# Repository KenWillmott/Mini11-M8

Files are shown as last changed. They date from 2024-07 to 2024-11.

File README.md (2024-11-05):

# Mini11-M8
MC68HC11A1 MCU based SBC

## IMPORTANT! This project is deprecated. It's superceded by this device:
https://github.com/KenWillmott/Mini11-M8E

This project is based on hardware and software developed here:
https://github.com/EtchedPixels/Mini11

# Overview
This is a 10cm * 10cm PCB with an MC68HC11A1 processor. It uses only traditional through hole PCB construction and MSI glue logic in the 74HC line. It does not have any programmable logic device other than the usual EEPROM. There is one exception, the reset controller is an SMD device. This is because of a noticeable cost/availability problem with through hole type reset controllers. To interface with additional peripherals, the board follows M8 sytem outline and mounting hole dimensions, and is equipped with a full bus interface that will connect with the M8 series of peripheral expansion PCB's available on this hosting.

The processor itself has a lot of built in features that make a self contained computer easier to make. The serial connection can connect to a host computer or some other device. The processor can support a TF memory card directly with software driving the built in SPI. That gives it a disk. To complement that there is 512kb of non volatile memory, battery backed up. Any 32k bank of this memory can be assigned to either the upper or lower 32k of the CPU memory map, by writing to the memory paging control latch. This essentially makes all the memory selectively available to the CPU.

The main memory is made non-volatile using a DS1210 NVRAM controller IC. An option is provided for either 128kb or 512kb of memory. Either one is a single IC. There is provision for either an on board or external battery, and also an auxiliary battery for additional protection or to allow hot swapping batteries.

# Memory Map
## Hardware
- 0000-7FFF  Bank 0 NVRAM
- 8000-EFFF  Bank 1 NVRAM
- F000-F03F  CPU control registers
- F040-F0FF  Internal RAM
- F100-F3FF  Bank 1 NVRAM
- F400-F7FF  Expansion Bus Device Select
- F800-FFFF  EPROM/EEPROM (read) / Memory Paging Register (write)
## Software
(current)
- 0000-EC00 dual bank general purpose memory
- EF80  stack
- EFC4-EFFF CPU vector jump table
- F800-FB5F Boot code
- FF80  I/O vector table
- FFD6-FFFF CPU vectors
## Operation
Currently, the system boots from the 2k ROM space. It sets up some system variables and then attempts to boot from SD. If a disk is found, it will load the first sector of disk into RAM and then run it. If SD is not used, the 2k block below the highest block can be programmed with a stand alone monitor. The upper and lower half of upper 4k of EEPROM is configured with a jumper on the PCB, so that a choice of boot routines can be made. The monitor is duplicated with the boot firmware, so is available for support in case the disk does not operate.

The CPU vectors in high ROM are copied into a vector table in RAM so that they can be redirected. simple serial I/O routines are in ROM, and can be used by applications by referencing the table in ROM where they are combined.

Memory banking is simple. The upper 4 bits of the memory latch select one of sixteen 32kb blocs from the 512kb main memory, that will appear in the upper 32k of CPU memory. Similarly, the lower 4 bits of the memory latch select an independent 32k bank from main memory, which appears in the lower 32k of CPU memory.
# Connectors
## J2 SPI/SD
Connects to the MCU SPI pins, mimics the common pinout of an SD/TF card adapter module (such as often used with Arduino). The module must have its own 3.3V/5V signal voltage translation on board. Many modules don't have that and can't tolerate 5V from the MCU
## J1 Serial
Typical TX/RX/VCC/GND connections usually to a USB to serial adapter module.
## J3 Parallel I/O
MCU Port A pins PA0-PA6 are presented at a connector (PA7 is used for an additional SD chip select)
## J6 Analog
MCU ADC inputs PE0-PE3, VCC and GND
# Jumpers
## JP4 Boot select
- 0: monitor
- 1: boot from SD card
## J7 BAT1
Place a jumper across two of the three pins to select:
- int: connects internal battery to the NVRAM controller
- ext: use to connect an external backup battery (3.0V) or a jumper to disable the NVRAM.
## J8 BAT2
Optionally connect an secondary, auxiliary backup battery. If this is powered, the on board battery may be changed without any data loss. Place a jumper if no battery is connected.
## JP3 512/128
- 512: use 512kb IC such as AS6C4008
- 128: use 128kb IC such as AS6C1008
## RES SW
provision for an external reset switch. Note that the MCU reset circuit is not common drain, it is a CMOS driven voltage level. Thus any reset signal must not be applied to the MCU/bus RESET signal line, only to the internal/external reset switch circuit that controls the reset controller IC.
## MODA, MODB
These are MCU mode control pins. They are held high with pull up resistors so are left open in normal operation.

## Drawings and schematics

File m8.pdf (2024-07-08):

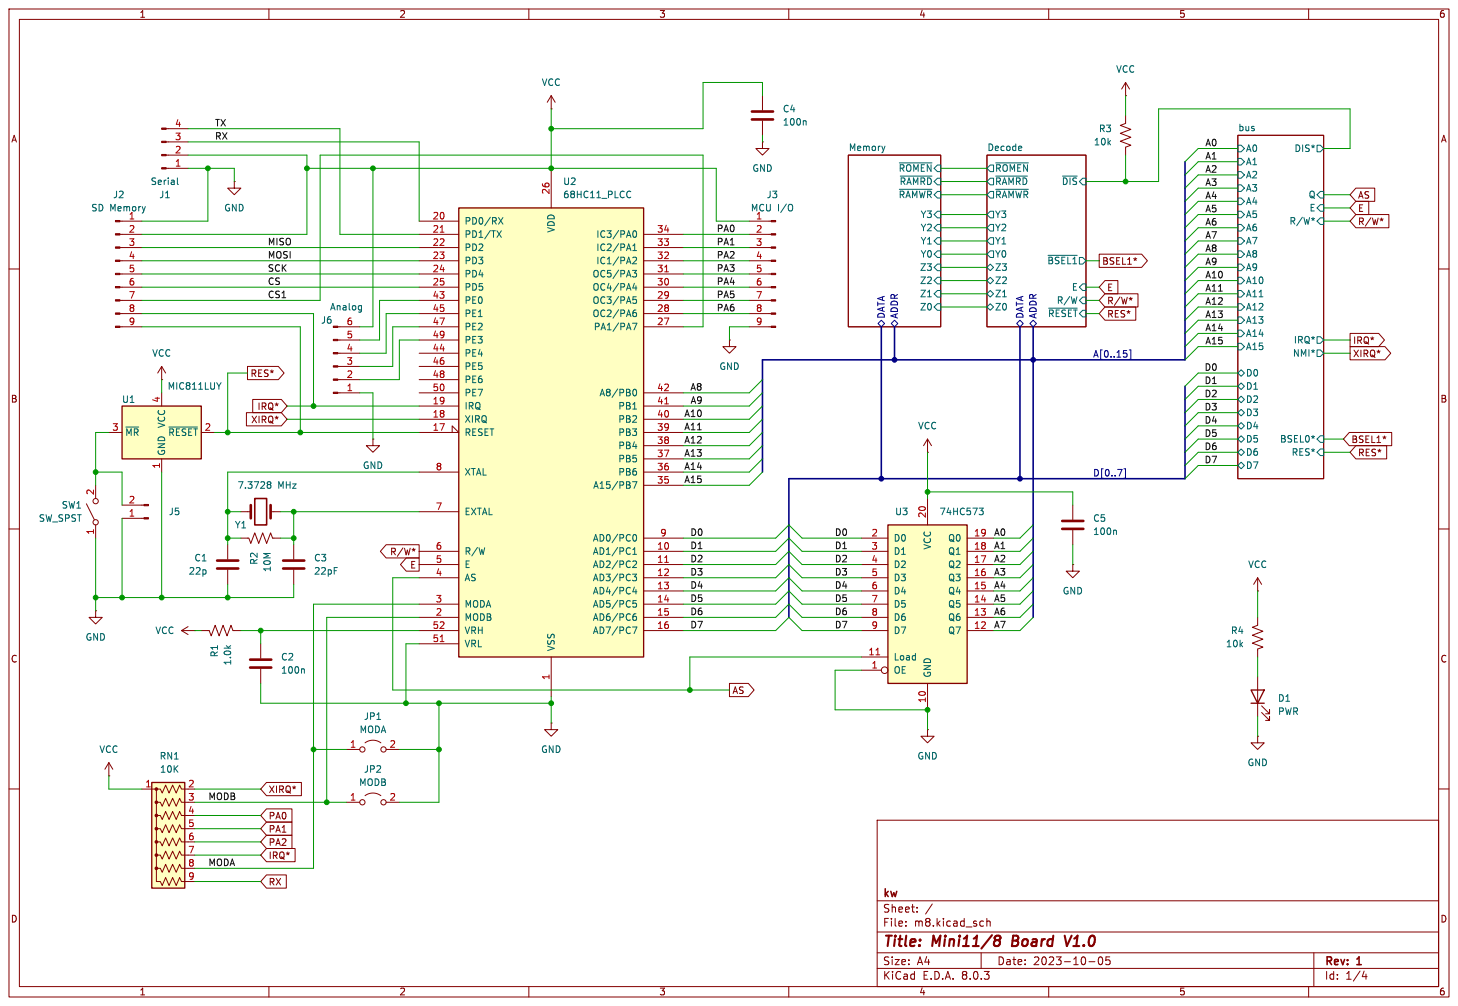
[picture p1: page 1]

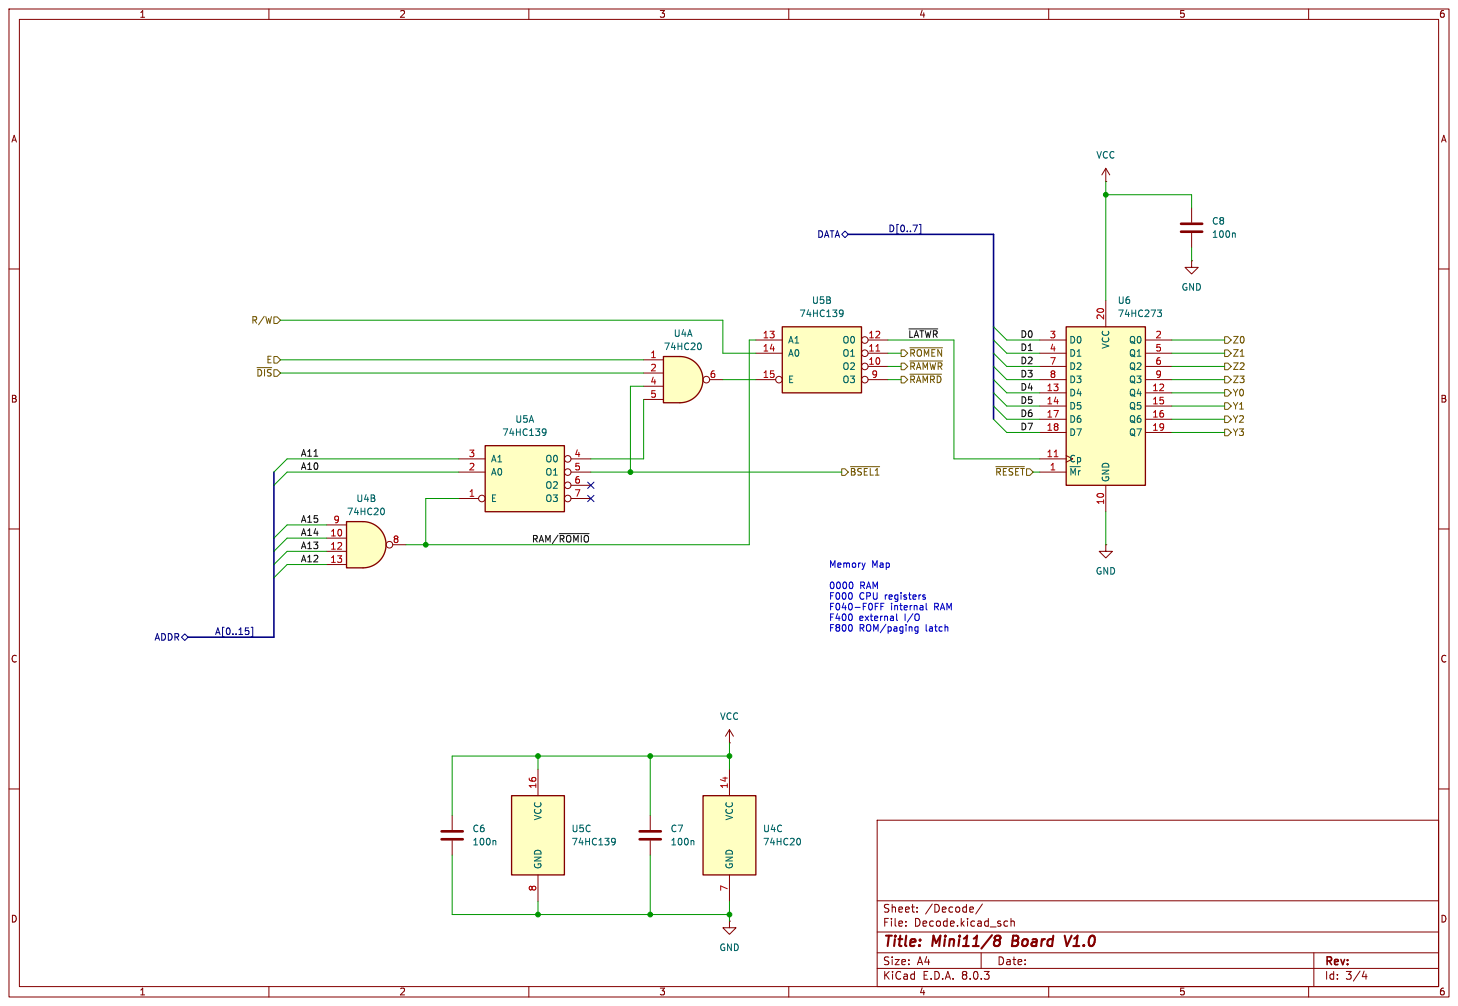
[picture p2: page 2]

File: Decode.kicad_sch Sheet: /Decode/ E

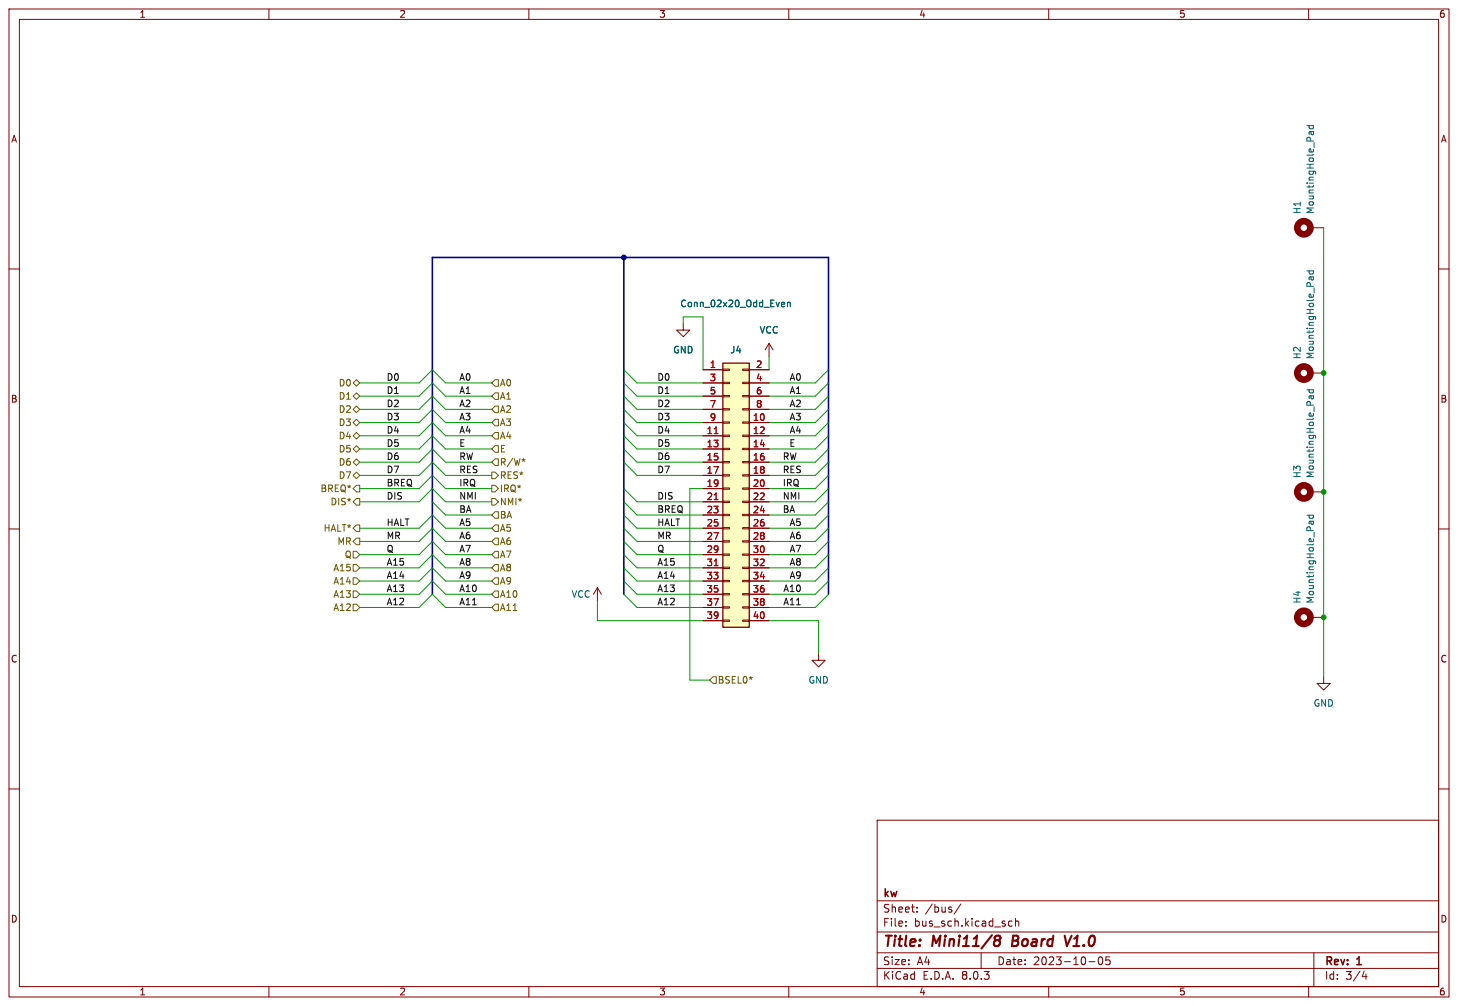
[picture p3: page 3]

File: bus_sch.kicad_sch Sheet: /bus/ kw 1

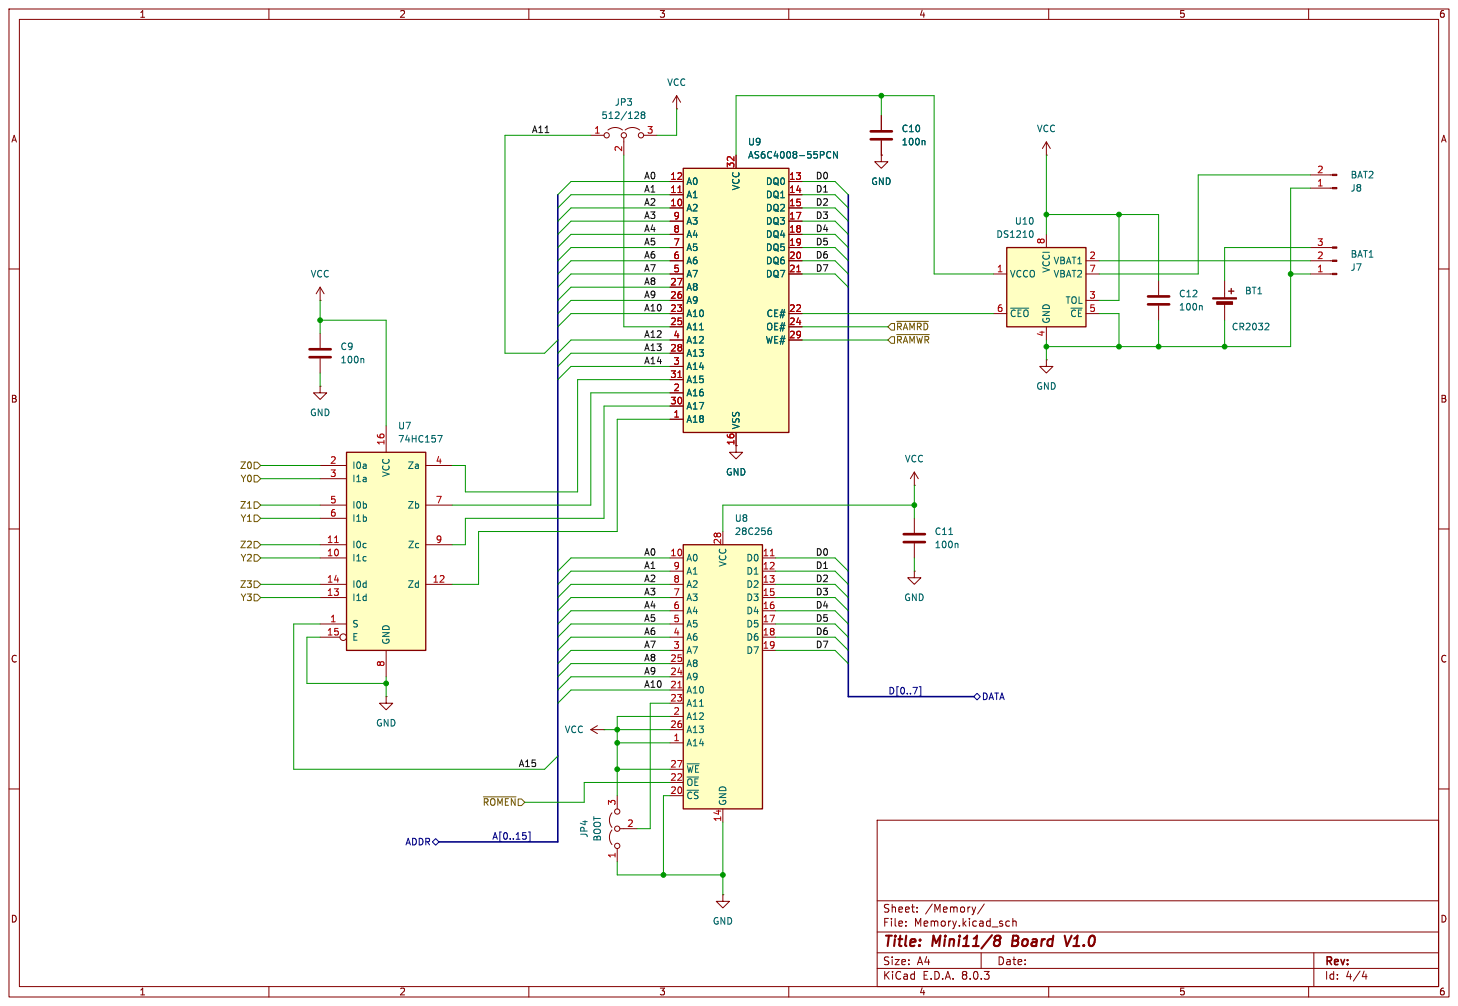
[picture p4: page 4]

File: Memory.kicad_sch Sheet: /Memory/ GND

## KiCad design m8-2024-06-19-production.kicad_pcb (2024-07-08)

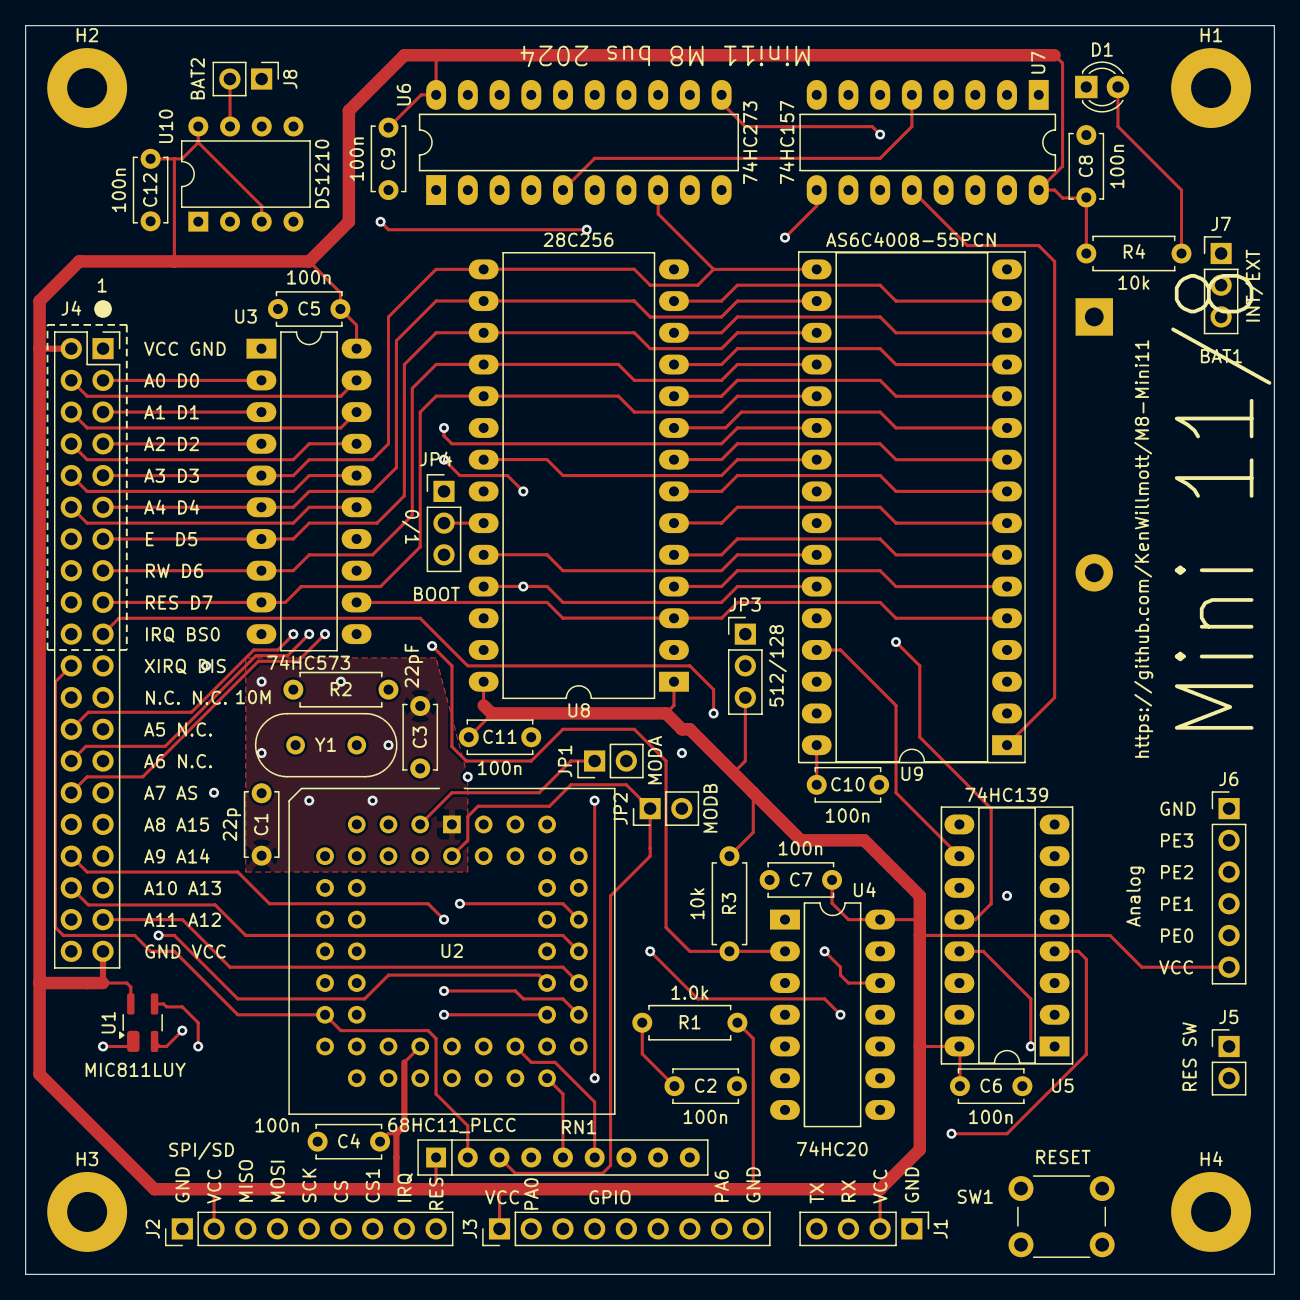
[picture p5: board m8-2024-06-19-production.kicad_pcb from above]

Board: 4 copper layers, 100.0 x 100.0 mm, 47 parts (1 on the bottom side), 85 nets.

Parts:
BT1: CR2032; BatteryHolder_Keystone_107_1x23mm
C1: 22p; C_Disc_D5.0mm_W2.5mm_P5.00mm
C2, C4, C5, C6, C7, C8, C9, C10, C11, C12: 100n; C_Disc_D5.0mm_W2.5mm_P5.00mm
C3: 22pF; C_Disc_D5.0mm_W2.5mm_P5.00mm
D1: PWR; LED_D3.0mm
H1, H2, H3, H4: MountingHole_Pad; MountingHole_3.2mm_M3_Pad
J1: Serial; PinHeader_1x04_P2.54mm_Vertical
J2: SD Memory; PinHeader_1x09_P2.54mm_Vertical
J3: MCU I/O; PinHeader_1x09_P2.54mm_Vertical
J4: Conn_02x20_Odd_Even; PinSocket_2x20_P2.54mm_Vertical
J5: Conn_01x02_Pin; PinHeader_1x02_P2.54mm_Vertical
J6: Analog; PinHeader_1x06_P2.54mm_Vertical
J7: BAT1; PinHeader_1x03_P2.54mm_Vertical
J8: BAT2; PinHeader_1x02_P2.54mm_Vertical
JP1: MODA; PinHeader_1x02_P2.54mm_Vertical
JP2: MODB; PinHeader_1x02_P2.54mm_Vertical
JP3: 512/128; PinHeader_1x03_P2.54mm_Vertical
JP4: BOOT; PinHeader_1x03_P2.54mm_Vertical
R1: 1.0k; R_Axial_DIN0207_L6.3mm_D2.5mm_P7.62mm_Horizontal
R2: 10M; R_Axial_DIN0207_L6.3mm_D2.5mm_P7.62mm_Horizontal
R3, R4: 10k; R_Axial_DIN0207_L6.3mm_D2.5mm_P7.62mm_Horizontal
RN1: 10K; R_Array_SIP9
SW1: RESET; SW_PUSH_6mm_H4.3mm
U1: MIC811LUY; SOT-143_Handsoldering
U2: 68HC11_PLCC; PLCC-52_THT-Socket
U3: 74HC573; DIP-20_W7.62mm_LongPads
U4: 74HC20; DIP-14_W7.62mm_LongPads
U5: 74HC139; DIP-16_W7.62mm_Socket_LongPads
U6: 74HC273; DIP-20_W7.62mm_LongPads
U7: 74HC157; DIP-16_W7.62mm_LongPads
U8: 28C256; DIP-28_W15.24mm_LongPads
U9: AS6C4008-55PCN; DIP-32_W15.24mm_Socket_LongPads
U10: DS1210; DIP-8_W7.62mm
Y1: 7.3728 MHz; Crystal_HC18-U_Vertical

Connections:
/A0: J4.4, U3.19 (Q0), U8.10 (A0), U9.12 (A0)
/A1: J4.6, U3.18 (Q1), U8.9 (A1), U9.11 (A1)
/A2: J4.8, U3.17 (Q2), U8.8 (A2), U9.10 (A2)
/A3: J4.10, U3.16 (Q3), U8.7 (A3), U9.9 (A3)
/A4: J4.12, U3.15 (Q4), U8.6 (A4), U9.8 (A4)
/A5: J4.26, U3.14 (Q5), U8.5 (A5), U9.7 (A5)
/A6: J4.28, U3.13 (Q6), U8.4 (A6), U9.6 (A6)
/A7: J4.30, U3.12 (Q7), U8.3 (A7), U9.5 (A7)
/A8: J4.32, U2.42 (A8/PB0), U8.25 (A8), U9.27 (A8)
/A9: J4.34, U2.41 (PB1), U8.24 (A9), U9.26 (A9)
/A10: J4.36, U2.40 (PB2), U5.2 (A0), U8.21 (A10), U9.23 (A10)
/A11: J4.38, JP3.1 (A), U2.39 (PB3), U5.3 (A1)
/A12: J4.37, U2.38 (PB4), U4.13, U9.4 (A12)
/A13: J4.35, U2.37 (PB5), U4.12, U9.28 (A13)
/A14: J4.33, U2.36 (PB6), U4.10, U9.3 (A14)
/A15: J4.31, U2.35 (A15/PB7), U4.9, U7.1 (S)
/CS: J2.6, U2.25 (PD5)
/CS1: J2.7, U2.27 (PA1/PA7)
/D0: J4.3, U2.9 (AD0/PC0), U3.2 (D0), U6.3 (D0), U8.11 (D0), U9.13 (DQ0)
/D1: J4.5, U2.10 (AD1/PC1), U3.3 (D1), U6.4 (D1), U8.12 (D1), U9.14 (DQ1)
/D2: J4.7, U2.11 (AD2/PC2), U3.4 (D2), U6.7 (D2), U8.13 (D2), U9.15 (DQ2)
/D3: J4.9, U2.12 (AD3/PC3), U3.5 (D3), U6.8 (D3), U8.15 (D3), U9.17 (DQ3)
/D4: J4.11, U2.13 (AD4/PC4), U3.6 (D4), U6.13 (D4), U8.16 (D4), U9.18 (DQ4)
/D5: J4.13, U2.14 (AD5/PC5), U3.7 (D5), U6.14 (D5), U8.17 (D5), U9.19 (DQ5)
/D6: J4.15, U2.15 (AD6/PC6), U3.8 (D6), U6.17 (D6), U8.18 (D6), U9.20 (DQ6)
/D7: J4.17, U2.16 (AD7/PC7), U3.9 (D7), U6.18 (D7), U8.19 (D7), U9.21 (DQ7)
/Decode/RAM/~ROMIO: U4.8, U5.1 (E), U5.13 (A1)
/Decode/Y0: U6.12 (Q4), U7.3 (I1a)
/Decode/Y1: U6.15 (Q5), U7.6 (I1b)
/Decode/Y2: U6.16 (Q6), U7.10 (I1c)
/Decode/Y3: U6.19 (Q7), U7.13 (I1d)
/Decode/Z0: U6.2 (Q0), U7.2 (I0a)
/Decode/Z1: U6.5 (Q1), U7.5 (I0b)
/Decode/Z2: U6.6 (Q2), U7.11 (I0c)
/Decode/Z3: U6.9 (Q3), U7.14 (I0d)
/Decode/~LATWR: U5.12 (O0), U6.11 (Cp)
/Decode/~RAMRD: U5.9 (O3), U9.24 (OE#)
/Decode/~RAMWR: U5.10 (O2), U9.29 (WE#)
/Decode/~ROMEN: U5.11 (O1), U8.22 (~OE)
/MISO: J2.3, U2.22 (PD2)
/MODA: JP1.1 (A), RN1.8 (R7), U2.3 (MODA)
/MODB: JP2.1 (A), RN1.3 (R2), U2.2 (MODB)
/MOSI: J2.4, U2.23 (PD3)
/PA3: J3.5, U2.31 (OC5/PA3)
/PA4: J3.6, U2.30 (OC4/PA4)
/PA5: J3.7, U2.29 (OC3/PA5)
/PA6: J3.8, U2.28 (OC2/PA6)
/SCK: J2.5, U2.24 (PD4)
/TX: J1.4, U2.21 (PD1/TX)
/bus/DIS: J4.21, R3.2, U4.2
AS: J4.29, U2.4 (AS), U3.11 (Load)
BSEL1*: J4.19, U4.4, U5.5 (O1)
E: J4.14, U2.5 (E), U4.1
GND: BT1.2 (-), C1.2, C2.2, C3.2, C4.2, C5.2, C6.2, C7.2, C8.2, C9.2, C10.2, C11.2, C12.2, D1.1 (K), H1.1, H2.1, H3.1, H4.1, J1.1, J2.1, J3.9, J4.1, J4.40, J5.1, J6.1, J7.1, J8.1, JP1.2 (B), JP2.2 (B), JP4.1 (A), SW1.1 (A), U1.1 (GND), U2.1 (VSS), U2.51 (VRL), U3.1 (OE), U3.10 (GND), U4.7 (GND), U5.8 (GND), U6.10 (GND), U7.8 (GND), U7.15 (E), U8.14 (GND), U8.20 (~CS), U9.16 (VSS), U10.4 (GND), U10.5 (~CE)
IRQ*: J2.8, J4.20, RN1.7 (R6), U2.19 (IRQ)
unnamed: BT1.1 (+), J7.3
unnamed: D1.2 (A), R4.2
unnamed: J5.2, SW1.2 (B), U1.3 (~MR)
unnamed: J6.2, U2.49 (PE3)
unnamed: J6.3, U2.47 (PE2)
unnamed: J6.4, U2.45 (PE1)
unnamed: J6.5, U2.43 (PE0)
unnamed: J7.2, U10.2 (VBAT1)
unnamed: J8.2, U10.7 (VBAT2)
unnamed: JP3.2 (C), U9.25 (A11)
unnamed: JP4.2 (C), U8.23 (A11)
unnamed: C3.1, R2.2, U2.7 (EXTAL), Y1.2
unnamed: C2.1, R1.2, U2.52 (VRH)
unnamed: C1.1, R2.1, U2.8 (XTAL), Y1.1
unnamed: U4.5, U5.4 (O0)
unnamed: U4.6, U5.15 (E)
unnamed: U7.4 (Za), U9.31 (A15)
unnamed: U7.7 (Zb), U9.2 (A16)
unnamed: U7.9 (Zc), U9.30 (A17)
unnamed: U7.12 (Zd), U9.1 (A18)
unnamed: C10.1, U9.32 (VCC), U10.1 (VCCO)
unnamed: U9.22 (CE#), U10.6 (~CEO)
PA0: J3.2, RN1.4 (R3), U2.34 (IC3/PA0)
PA1: J3.3, RN1.5 (R4), U2.33 (IC2/PA1)
PA2: J3.4, RN1.6 (R5), U2.32 (IC1/PA2)
RES*: J2.9, J4.18, U1.2 (~RESET), U2.17 (RESET), U6.1 (~Mr)
RX: J1.3, RN1.9 (R8), U2.20 (PD0/RX)
R/W*: J4.16, U2.6 (R/W), U5.14 (A0)
VCC: C4.1, C5.1, C6.1, C7.1, C8.1, C9.1, C11.1, C12.1, J1.2, J2.2, J3.1, J4.2, J4.39, J6.6, JP3.3 (B), JP4.3 (B), R1.1, R3.1, R4.1, RN1.1 (common), U1.4 (VCC), U2.26 (VDD), U3.20 (VCC), U4.14 (VCC), U5.16 (VCC), U6.20 (VCC), U7.16 (VCC), U8.1 (A14), U8.2 (A12), U8.26 (A13), U8.27 (~WE), U8.28 (VCC), U10.3 (TOL), U10.8 (VCCI)
XIRQ*: J4.22, RN1.2 (R1), U2.18 (XIRQ)

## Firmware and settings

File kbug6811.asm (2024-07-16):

; KBUG V 1.04
; Monitor program for the HD6303Y EVB board

; K. Willmott 2023
; tested, working

; minibug originally modified for NMIS-0021

; 2023-03-01 adapt for 6303Y
; 2023-05-18 first clean up, add some comments
; 2023-05-20 add feedback text, write "W", exec command "X"
; 2023-05-21 fixed stack initialization error
; 2023-05-22 add CPU vector jump table
; 2023-05-25 add primitive RAM test
; 2023-06-18 add external baud clock for 3MHz operation
; 2023-06-19 make alpha input case insensitive
; 2023-06-22 add clock stretching
; 2023=07-14 code formatting clean up
; 2023-10-20 add S record address relocation

; *******************************
; 2024-07-03 adapt for 68HC11A1
; *******************************

; 2024-07-04 add CPU vectors
; 2024-07-11 maintenance
; 2024-07-14 convert to disk loaded

; based on the original source
; COPYWRITE 1973, MOTOROLA INC
; REV 004 (USED WITH MIKBUG)

;***************
;   SYSTEM HARDWARE SPECIFIC EQUATES   *
;***************

; configuration:

FENCE	EQU	$EC00	; lowest free RAM, 768 byte stack is above
APPSIZ	EQU	$0400	; slightly larger than the KBUG monitor
VECTAB	EQU	$EFC4	; CPU vector jump table
STKINI	EQU	$EF7F	; initial stack pointer

; standard routines in ROM:

GETCH	EQU	$FB46	; print char
OUTCH	EQU	$FB2E	; input char, no echo
PRSTRN	EQU	$FB3A	; print string
PHEX	EQU	$FB1C	; print hex pair
DHEX	EQU	$FB26	; print hex digit
PRDIG	EQU	$FB2C	; print decimal digit

; more

RAMBS		equ	$0000		; start of system ram
RAMEND		equ	FENCE-APPSIZ		;memory limit

IRAMBS		equ	$F000               ; start of internal ram
IRAMND		equ	$F100               ; end of internal ram
REGBS		equ	$F000               ; start of registers (0,x)
ROMBS		equ	$F800               ; start of rom
MEMLAT		EQU	ROMBS		; shared, ROM and write latch

; Address of boot or test code, RTS to return to monitor
XCALL		equ	$0000		;call test code here

NUMVEC		equ	20	; number of CPU vectors to create
NUMREG		equ	11	; number of CPU registers

; Register flag definitions:

TDRE	equ	$80
RDRF	equ	$20


; MC68HC11A1 register definitions:
; from buf25.asm buffalo source
; existing defines added

PORTA	EQU	$00
		; $01 reserved
PIOC	EQU	$02
PORTC	EQU	$03
PORTB	EQU	$04
PORTCL	EQU	$05
		; $06 reserved
DDRC	EQU	$07
PORTD	EQU	$08
DDRD	EQU	$09
PORTE	equ	$0A           ; port e
CFORC	EQU	$0B
OC1M	EQU	$0C
OC1D	EQU	$0D
TCNT	equ	$0E           ; timer count
TIC1	EQU	$10
TIC2	EQU	$12
TIC3	EQU	$14
TOC1	EQU	$16
TOC2	EQU	$18
TOC3	EQU	$1A
TOC4	EQU	$1C
TOC5	equ	$1E           ; oc5 reg
TCTL1	equ	$20           ; timer control 1
TCTL2	equ	$21           ; timer control 2
TMSK1	equ	$22           ; timer mask 1
TFLG1	equ	$23           ; timer flag 1
TMSK2	equ	$24           ; timer mask 2
PACTL	EQU	$26
PACNT	EQU	$27
SPCR	EQU	$28
SPSR	EQU	$29
SPDR	EQU	$2A
BAUD	equ	$2B           ; sci baud reg
SCCR1	equ	$2C           ; sci control1 reg
SCCR2	equ	$2D           ; sci control2 reg
SCSR	equ	$2E           ; sci status reg
SCDR	equ	$2F           ; sci data reg
ADCTL	EQU	$30
ADR1	EQU	$31
ADR2	EQU	$32
ADR3	EQU	$33
ADR4	EQU	$34
		; $35-$38 reserved
OPTION	equ	$39           ; option reg
COPRST	equ	$3A           ; cop reset reg
PPROG	equ	$3B           ; ee prog reg
HPRIO	equ	$3C           ; hprio reg
INIT	equ	$3D           ; RAM and IO mapping reg
TEST1	EQU	$3E
CONFIG	equ	$3F           ; config register

; start of code area

	org	RAMEND

; ENTER POWER ON SequENCE

START:

	;	point X to the RAM/IO space
	LDX	#$F000

; end of hardware initialization
; exit conditions:
; X = $F000 pointer to I/O and IRAM
; S = high RAM below system scratchpad
; contiguous SRAM configured from $0000 to FENCE if installed

; run main program

	jmp	KBUG

; Utility routines follow
;

; Make input case insensitive
; From p.718 Hitachi HD6301-3 Handbook

TPR:	cmpa	#'a'	;Entry point
	bcs	TPR1
	cmpa	#'z'
	bhi	TPR1
	anda	#$DF	;Convert lowercase to uppercase
TPR1:	rts

; Input a character with output echo

INCH:	jsr	GETCH
	bsr	TPR
	cmpa	#$0D
	beq	NOECHO
	JSR	OUTCH
NOECHO: RTS

; boot time memory test

MEMTST:	ldy	#RAMBS
	sty	memtop

loop:	ldaa	0,y	; get byte
	coma		; invert bits
	tab		; save inverted copy in B

	staa	0,y	; save complement same place
	cmpb	0,y
	bne	done	; read not same as written

	coma		; invert again
	staa	0,y	; save original value same place

	iny		; look at next byte
	cpy	#RAMEND
	beq	done
	bra	loop

done:	sty	memtop
	rts
;
; end utility routines


; Monitor code begins
;

; INPUT HEX CHAR
;

INHEX:	bsr	INCH
	cmpa	#'0'
	bmi	C1       ;NOT HEX
	cmpa	#'9'
	ble	IN1HG    ;IS HEX
	cmpa	#'A'
	bmi	C1       ;NOT HEX
	cmpa	#'F'
	bgt	C1       ;NOT HEX
	suba	#'A'-'9'-1    ;MAKE VALUES CONTIGUOUS
IN1HG:	rts

; S-record loader
;

LOAD:	bsr	INCH
	cmpa	#'S'
	bne	LOAD    ;1ST CHAR NOT (S)
	bsr	INCH
	cmpa	#'9'
	beq	C1
	cmpa	#'1'
	bne	LOAD    ;2ND CHAR NOT (1)
	clr	CKSM     ;ZERO CHECKSUM
	bsr	BYTE     ;READ BYTE
	suba	#2
	staa	BYTECT   ;BYTE COUNT

; BUILD ADDRESS
	bsr	BADOFF

; STORE DATA
LOAD11:	bsr	BYTE
	dec	BYTECT
	beq	LOAD15   ;ZERO BYTE COUNT
	staa	,y        ;STORE DATA
	iny
	bra	LOAD11

LOAD15:	inc	CKSM
	beq	LOAD
LOAD19:	ldaa	#'?'      ;PRINT QUESTION MARK

	jsr	OUTCH
C1:	jmp	CONTRL

; BUILD ADDRESS
;

BADOFF:	bsr	BYTE     ;READ 2 FRAMES
	adda	srecof	; add high order address offset
	bra	BAD2

BADDR:	bsr	BYTE     ;READ 2 FRAMES
BAD2:	staa	XHI
	bsr	BYTE
	staa	XLOW
	ldy	XHI      ;Y := ADDRESS WE BUILT
	rts

; INPUT BYTE (TWO FRAMES)
;

BYTE:	bsr	INHEX    ;GET HEX CHAR
	asla
	asla
	asla
	asla
	tab
	bsr	INHEX
	anda	#$0F     ;MASK TO 4 BITS
	aba
	tab
	addb	CKSM
	stab	CKSM
	rts

; CHANGE MEMORY (M AAAA DD NN)
;

CHANGE:	bsr	BADDR    ;BUILD ADDRESS
	bsr	OUTS     ;PRINT SPACE
	bsr	OUT2HS
	bsr	BYTE
	dey
	staa	,y
	cmpa	,y
	bne	LOAD19   ;MEMORY DID NOT CHANGE
	bra	CONTRL

; WRITE MEMORY (M AAAA NN)
;

MWRITE:	bsr	BADDR    ;BUILD ADDRESS
	bsr	OUTS     ;PRINT SPACE
	bsr	BYTE
	staa	,y
	bra	CONTRL

;  formatted output entry points
;

OUTHL:	lsra	;OUT HEX LEFT BCD DIGIT
	lsra
	lsra
	lsra

OUTHR:	anda	#$F	;OUT HEX RIGHT BCD DIGIT
	adda	#$30
	cmpa	#$39
	bhi	ISALF
	jmp	OUTCH

ISALF:	adda	#$7
	jmp	OUTCH

OUT2H:	ldaa	0,y      ;OUTPUT 2 HEX CHAR
	bsr	OUTHL    ;OUT LEFT HEX CHAR
	ldaa	0,y
	bsr	OUTHR    ;OUT RIGHT HEX VHAR
	iny
	rts

OUT2HS:	bsr	OUT2H    ;OUTPUT 2 HEX CHAR + SPACE
OUTS:	ldaa	#$20     ;SPACE
	jmp	OUTCH    ;(bsr & rts)

; Monitor startup
;

KBUG:	jsr	MEMTST	;check memory

	ldy	#MOTD		;Print start up message
	jsr	PRSTRN

	ldy	#MMSG1	;Print memtest results
	jsr	PRSTRN
	ldy	#memtop
	jsr	OUT2H
	jsr	OUT2H
	ldy	#MMSG2
	jsr	PRSTRN

	ldy	#cmdhlp   ;Print commands message
	jsr	PRSTRN

	clra
	staa	srecof	;initialize S record offset

	bra	CONTRL


; PRINT CONTENTS OF STACK

PRINT:	ldy	#REGHDR   ;Print register titles
	jsr	PRSTRN
	tsy
	sty	SP       ;SAVE STACK POINTER
	ldab	#11
PRINT2:	bsr	OUT2HS   ;OUT 2 HEX & SPACE
	DECB
	bne	PRINT2
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
